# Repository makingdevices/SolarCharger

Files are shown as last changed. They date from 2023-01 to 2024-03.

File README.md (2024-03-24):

<!-- Improved compatibility of back to top link: See: https://github.com/othneildrew/Best-README-Template/pull/73 -->

<!--
*** Thanks for checking out the Best-README-Template. If you have a suggestion
*** that would make this better, please fork the repo and create a pull request
*** or simply open an issue with the tag "enhancement".
*** Don't forget to give the project a star!
*** Thanks again! Now go create something AMAZING! :D
-->

<!-- PROJECT SHIELDS -->
<!--
*** I'm using markdown "reference style" links for readability.
*** Reference links are enclosed in brackets [ ] instead of parentheses ( ).
*** See the bottom of this document for the declaration of the reference variables
*** for contributors-url, forks-url, etc. This is an optional, concise syntax you may use.
*** https://www.markdownguide.org/basic-syntax/#reference-style-links
-->
[][ig-url]
[][sponsor-url]
[][stars-url]
[][issues-url]
[][linkedin-url]

<!-- PROJECT LOGO -->
<br />
<div align="center">
  <a href="https://makingdevices.com/links/">
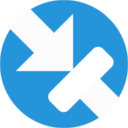
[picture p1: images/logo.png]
    
  </a>

<h3 align="center">Making Devices</h3>

  <p align="center">
    Open Source projects where we struggle with engineering, electronics, coding and who knows what else... The solar charger uses the energy from a solar panel (using MPPT) to charge a Li-Ion rechargeable battery and provide an stable 5V - 0.6A output.
  </p>
</div>

<!-- TABLE OF CONTENTS -->
<details>
  <summary>Table of Contents</summary>
  <ol>
    <li>
      <a href="#about-the-project">About The Project</a>
      <ul>
        <li><a href="#built-with">Built With</a></li>
      </ul>
    </li>
    <li>
      <a href="#Build-one">Build one</a>
      <ul>
      </ul>
    </li>
    <li><a href="#usage">Usage</a></li>
    <li><a href="#roadmap">Roadmap</a></li>
    <li><a href="#license">License</a></li>
    <li><a href="#contact">Contact</a></li>
    <li><a href="#Sponsor">Sponsor</a></li>
  </ol>
</details>

<!-- ABOUT THE PROJECT -->
## About The Project

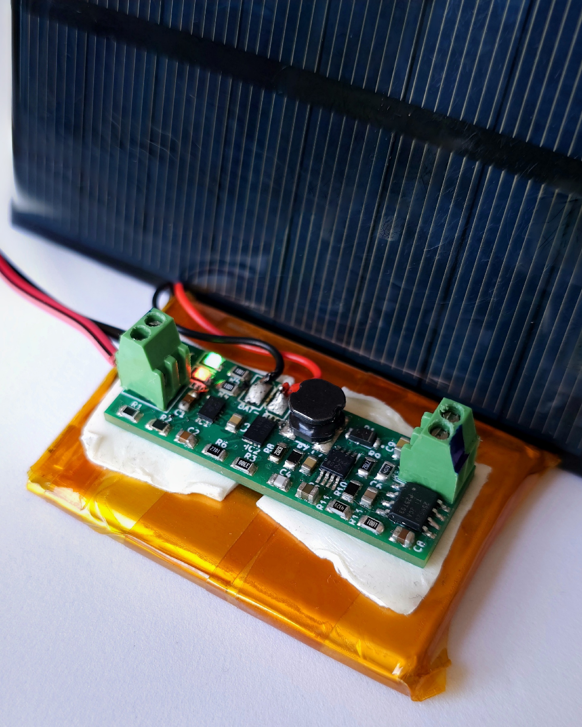
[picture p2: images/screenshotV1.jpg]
Bytes Counter Shot
[](https://github.com/makingdevices/SolarCharger)

The solar charger uses the energy from a solar panel (using MPPT) to charge a Li-Ion rechargeable battery and provide an stable 5V - 0.6A output. The project was created to test a small circuit before using it with other projects. 

<p align="right">(<a href="#readme-top">back to top</a>)</p>

### Built With

[][kicad-url]
[][sponsor-url]

<p align="right">(<a href="#readme-top">back to top</a>)</p>

<!-- GETTING STARTED -->

## Build one
Documentation is updated.

1. Get the gerber files for the latest version: [V1.0](https://github.com/makingdevices/SolarCharger/blob/main/Gerber/SolarCharger_v1.zip) 
2. Send them to a PCB manufacturer ([Our Sponsor is PCBWAY][sponsor-url])
3. You should solder all the components in the board. ([The schematic is available here v1.0][schematic-url])

<p align="right">(<a href="#readme-top">back to top</a>)</p>

<!-- USAGE EXAMPLES -->
## Usage

As soon as you connect a battery, the output voltage will be activated. 

Protections:

- Solar Panel
  - Input voltage from 3V to 20V. It has over-voltage protection (OVP).
  - NTC Sensor: The charging process is compatible with the JEITA temperature standard for Li-Ion batteries, limiting the charge of the battery depending of the temperature of it.
  - Protection for short-circuit in the battery.

- Battery
  - Overcharge Detection Voltage at 4.2V (25mV accuracy)
  - Overcharge Hysteresis Voltage Range. (Release at 4.1V)
  - Overdischarge Detection Voltage at 2.5V.
  - Overdischarge Hysteresis Voltage Range. (Release at 3.0V)
  - Discharge overcurrent detection voltage. 
  - Short current detection voltage.    
  Note: You may want to select a different AP9214 configuration depending of your battery type. We have tested the AP9214L-AE-HSB.

- Output
  - Voltage fixed at 5V +-1.5%
  - Undervoltage protection. 
  - Overvoltage protection at 5.7V
  - Overcurrent and shortcircuit protection (+1A). It will recuperate when the shortcircuit is released. 

<p align="right">(<a href="#readme-top">back to top</a>)</p>

<!-- ROADMAP -->
## Roadmap

- [x] Assembly New Board
- [x] Test with electronic Load.
- [x] Validate ratings

See the [open issues](https://github.com/makingdevices/SolarCharger/issues) for a full list of proposed features (and known issues).

State: Project <b>FINISHED</b> - 12/09/2023

Priority: <b>High</b>

<p align="right">(<a href="#readme-top">back to top</a>)</p>

<!-- LICENSE -->
## License

Distributed under three licenses:
- [Hardware](/License/HW_cern_ohl_s_v2.pdf)
- [Software](/License/SW_GPLv3.0.txt)
- [Documentation](/License/Documentation_CC-BY-SA-4.0.txt)

[GPL v3 License][license-url] 
<p align="right">(<a href="#readme-top">back to top</a>)</p>

<!-- CONTACT -->
## Contact

Making Devices - [@MakingDevices](https://www.instagram.com/makingdevices/)

Project Link: [https://github.com/makingdevices/SolarCharger](https://github.com/makingdevices/SolarCharger/)

Other Links: [LinkTree](https://makingdevices.com/links/)

<p align="right">(<a href="#readme-top">back to top</a>)</p>

<!-- Sponsor -->
## Sponsor

[PCBWAY](https://www.pcbway.com/?from=makingdevices) is the most professional PCB manufacturer for prototyping and low-volume production to work with in the world. With more than a decade in the field, They are committed to meeting the needs of their customers from different industries in terms of quality, delivery, cost-effectiveness and any other demanding requests. As Sponsor of Making Devices, they will be in charge of all the PCBs for MDV, allowing both of us to grow together in a long term partnership. We hope you take them into account for your both personal and professional prototypes or products.

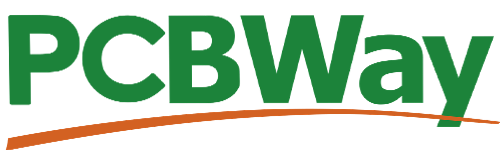
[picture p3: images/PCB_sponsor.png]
Sponsor Shot
[][sponsor-url]

<!-- MARKDOWN LINKS & IMAGES -->
<!-- https://www.markdownguide.org/basic-syntax/#reference-style-links -->
[contributors-shield]: https://img.shields.io/github/contributors/makingdevices/SolarCharger.svg?style=for-the-badge
[contributors-url]: https://github.com/makingdevices/SolarCharger/graphs/contributors
[forks-shield]: https://img.shields.io/github/forks/makingdevices/SolarCharger.svg?style=for-the-badge
[forks-url]: https://github.com/makingdevices/SolarCharger/network/members
[stars-shield]: https://img.shields.io/github/stars/makingdevices/SolarCharger.svg?style=for-the-badge
[stars-url]: https://github.com/makingdevices/SolarCharger/stargazers
[issues-shield]: https://img.shields.io/github/issues/makingdevices/SolarCharger.svg?style=for-the-badge
[issues-url]: https://github.com/makingdevices/SolarCharger/issues
[license-shield]: /images/license.png
[license-url]: https://github.com/makingdevices/SolarCharger/tree/main/License
[linkedin-shield]: https://img.shields.io/badge/-LinkedIn-black.svg?style=for-the-badge&logo=linkedin&colorB=555
[linkedin-url]: https://www.linkedin.com/company/making-devices/
[sponsor-shield]: https://img.shields.io/badge/SPONSOR-PCBWAY-black.svg?style=for-the-badge&colorB=1200
[sponsor-url]: https://www.pcbway.com/?from=makingdevices
[sponsor-screenshot]: /images/PCB_sponsor.png
[product-screenshot]: images/screenshotV1.jpg
[PIC]: https://img.shields.io/badge/PIC18LF45K50-000000?style=for-the-badge
[PIC-url]: http://ww1.microchip.com/downloads/en/devicedoc/40001350f.pdf
[kicad-shield]: https://img.shields.io/badge/kicad-0b03fc?style=for-the-badge&logo=kicad&logoColor=white
[kicad-url]: https://www.kicad.org/
[YT-screenshot]: images/YT_assembly.PNG
[sponsor-icon]:  https://img.shields.io/badge/-PCBWAY-black.svg?style=for-the-badge&colorB=1200
[ig-shield]: https://img.shields.io/badge/instagram-a83297?style=for-the-badge&logo=instagram&logoColor=white
[ig-url]: https://www.instagram.com/makingdevices/
[MPLAB-C]: https://img.shields.io/badge/MPLAB%20C18-DD0031?style=for-the-badge&logo=C&logoColor=white
[MPLAB-C-url]: https://www.microchip.com/en-us/development-tool/SW006011
[Svelte.dev]: https://img.shields.io/badge/Svelte-4A4A55?style=for-the-badge&logo=svelte&logoColor=FF3E00
[Svelte-url]: https://svelte.dev/
[Laravel.com]: https://img.shields.io/badge/Laravel-FF2D20?style=for-the-badge&logo=laravel&logoColor=white
[Laravel-url]: https://laravel.com
[Bootstrap.com]: https://img.shields.io/badge/Bootstrap-563D7C?style=for-the-badge&logo=bootstrap&logoColor=white
[Bootstrap-url]: https://getbootstrap.com
[JQuery.com]: https://img.shields.io/badge/jQuery-0769AD?style=for-the-badge&logo=jquery&logoColor=white
[JQuery-url]: https://jquery.com 
[schematic-url]: /Output_PDF/schematic_V1.pdf

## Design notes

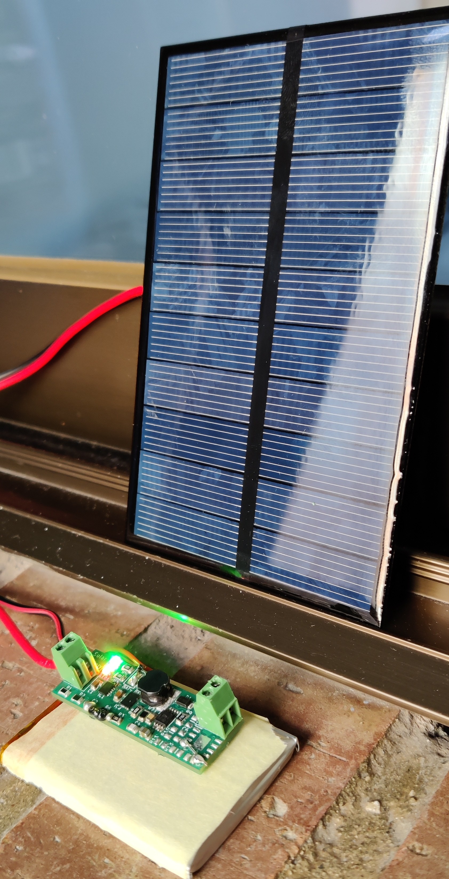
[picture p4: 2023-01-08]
images/screenshot.jpg

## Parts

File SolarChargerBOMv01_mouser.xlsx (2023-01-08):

Part | Info | Qty. | Unit Price | Ext. Price | Mouser Ref | Link
BQ24210DQCR | Charging IC | 1 | $2.4900 | $2.4900 | 595-BQ24210DQCR
NTC 10K 5% | NTC | 1 | $1.1500 | $1.1500 | 279-NTC0805J10K
Resistor 780 |  | 1 | $0.2980 | $0.2980 | 667-ERA-6AEB8060V
Resistor 21.5k |  | 1 | $0.1580 | $0.1580 | 71-CRCW0805-21.5K-E3
resistor 1k |  | 2 | $0.0880 | $0.1760 | 603-RC0805FR-071KL
Capacitor 1uF |  | 2 | $0.1930 | $0.3860 | 581-0805YG105Z
TPS61085 | Step-up 2A | 1 | $2.0700 | $2.0700 | 595-TPS61085TDGKR
FSV360FP | Schottky diode | 1 | $0.4460 | $0.4460 | 512-FSV360FP
47uH Inductor | Coil | 1 | $0.5160 | $0.5160 | 652-SRN6045-4R7Y
Resistor 330 |  | 1 | $0.2280 | $0.2280 | 652-CMP0805AFX-3300L
Resistor 2.7k |  | 1 | $0.1310 | $0.1310 | 71-CRCW0805-2.7K
Resistor 44.2k |  | 1 | $0.1580 | $0.1580 | 71-CRCW0805-44.2K-E3
Resistor 27k |  | 1 | $0.1050 | $0.1050 | 603-RT0805FRE1327KL
Resistor 82k |  | 1 | $0.0880 | $0.0880 | 603-RC0805FR-0782KL
Capacitor 22uF | 6.3VDC | 1 | $0.2450 | $0.2450 | 963-JMK212BBJ226MG8T
Capacitor 820pF | 50VDC | 1 | $0.3060 | $0.3060 | 581-08055A821K
Capacitor 47uF |  | 1 | $1.0900 | $1.0900 | 581-0805ZD476MAT2A
Capacitor 100nF |  | 1 | $0.1400 | $0.1400 | 581-08055C104K
AP9214L | Battery Prot. IC | 1 | $0.8400 | $0.8400 | 621-AP9214L-AN-HSBR7
TPS259620DDAR | eFuse | 1 | $0.8050 | $0.8050 | 595-TPS259620DDAR
Resistor 450k |  | 1 | $0.1580 | $0.1580 | 71-CRCW0805453KFKEA
Resistor 432k |  | 1 | $0.0880 | $0.0880 | 652-CR0805FX-4323ELF
Capacitor 2.2nF |  | 1 | $0.2360 | $0.2360 | 80-C0805C222K2GECTU
Capacitor 100uF |  | 1 | $0.1140 | $0.0960 | 80-C0805C104K5RACLR
Resistor 400k |  | 1 | $0.0960 | $0.0880 | 667-ERJ-6ENF4023V
Resistor 909 |  | 1 | $0.0880 | $0.0880 | 652-CR0805FX-9090ELF
Connector 2P | Screw terminals | 2 | $1.1200 | $2.2400 | 571-282834-2
 |  |  |  | Total: | $14.8200

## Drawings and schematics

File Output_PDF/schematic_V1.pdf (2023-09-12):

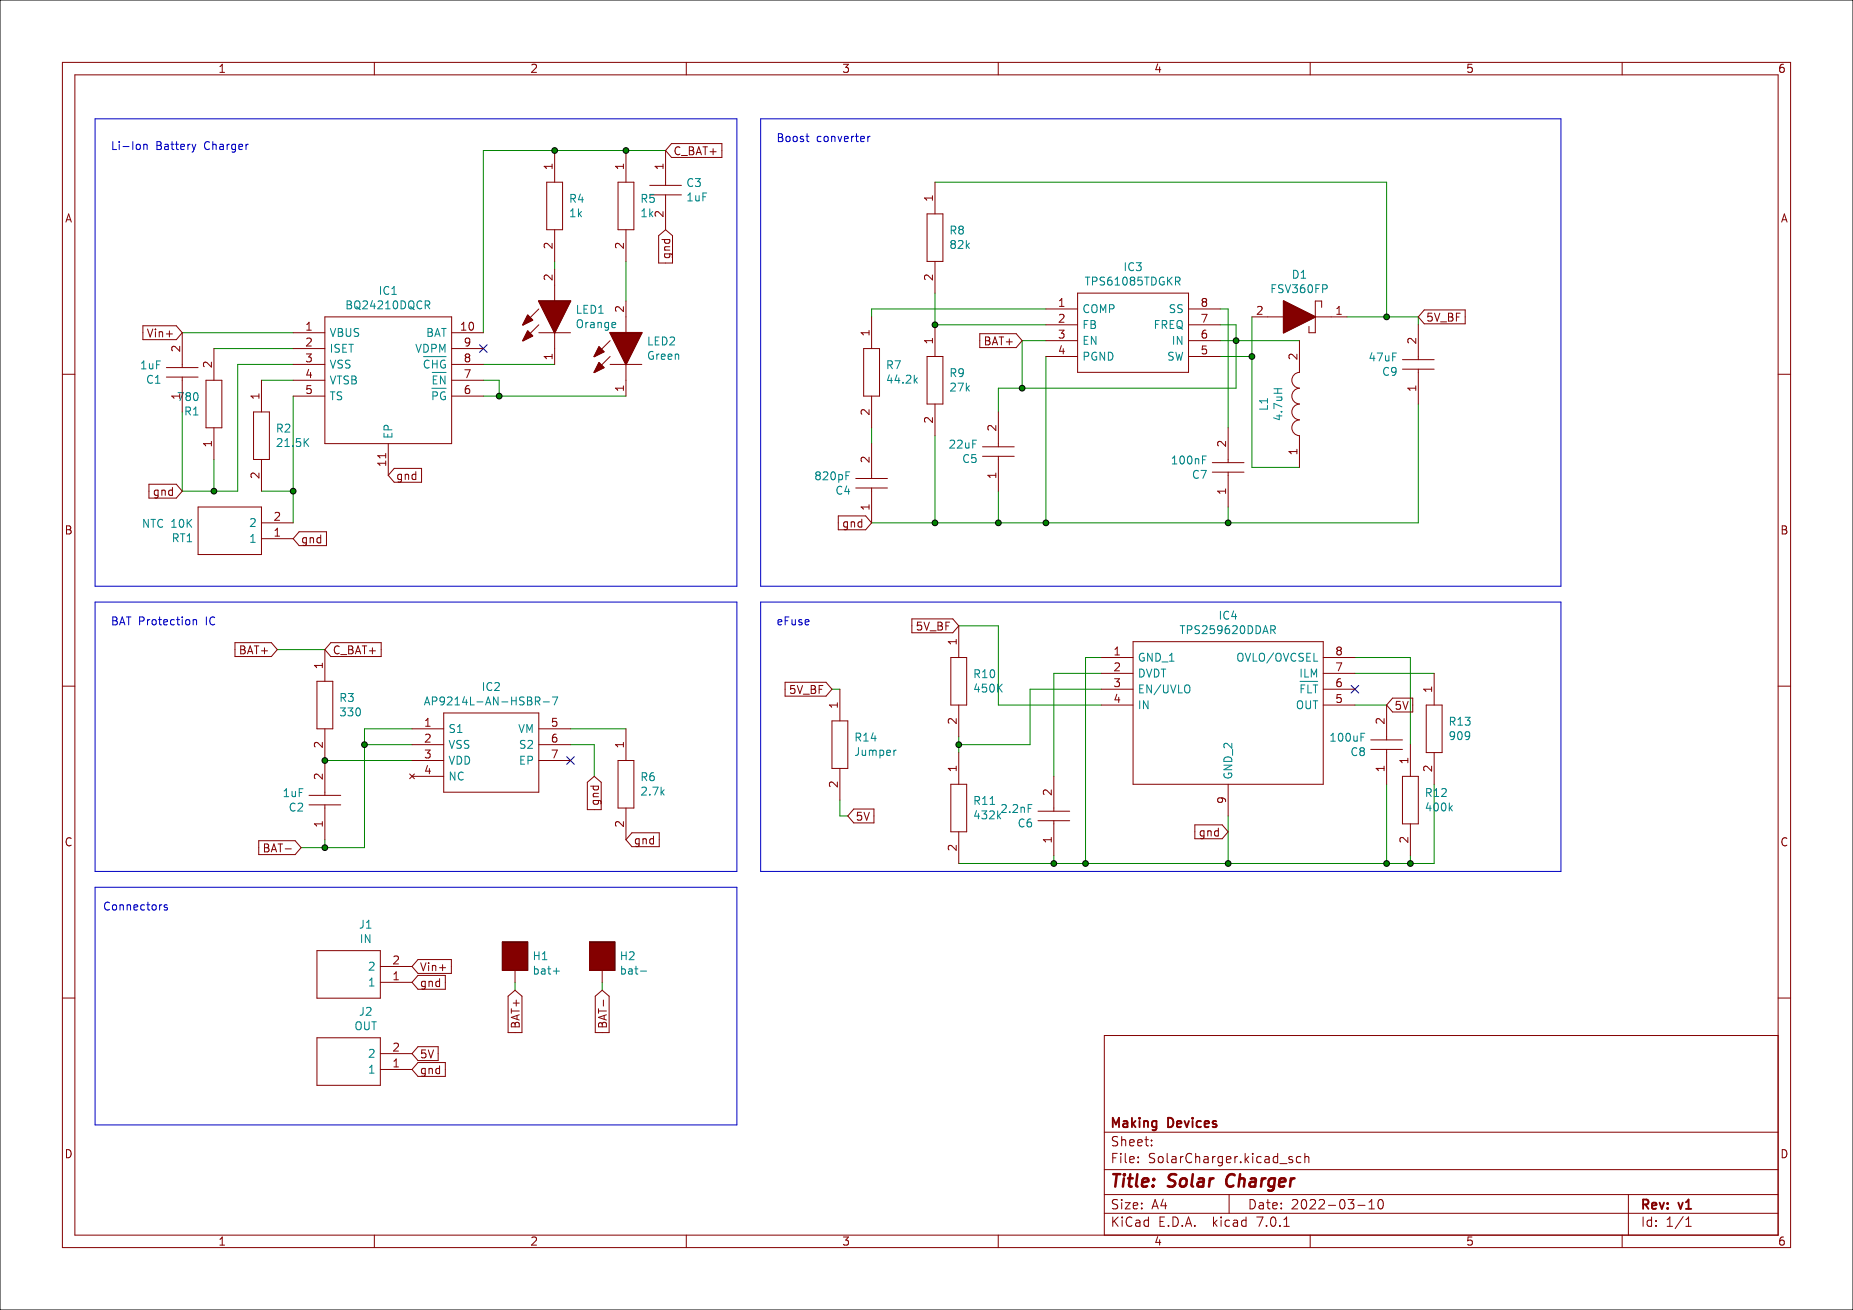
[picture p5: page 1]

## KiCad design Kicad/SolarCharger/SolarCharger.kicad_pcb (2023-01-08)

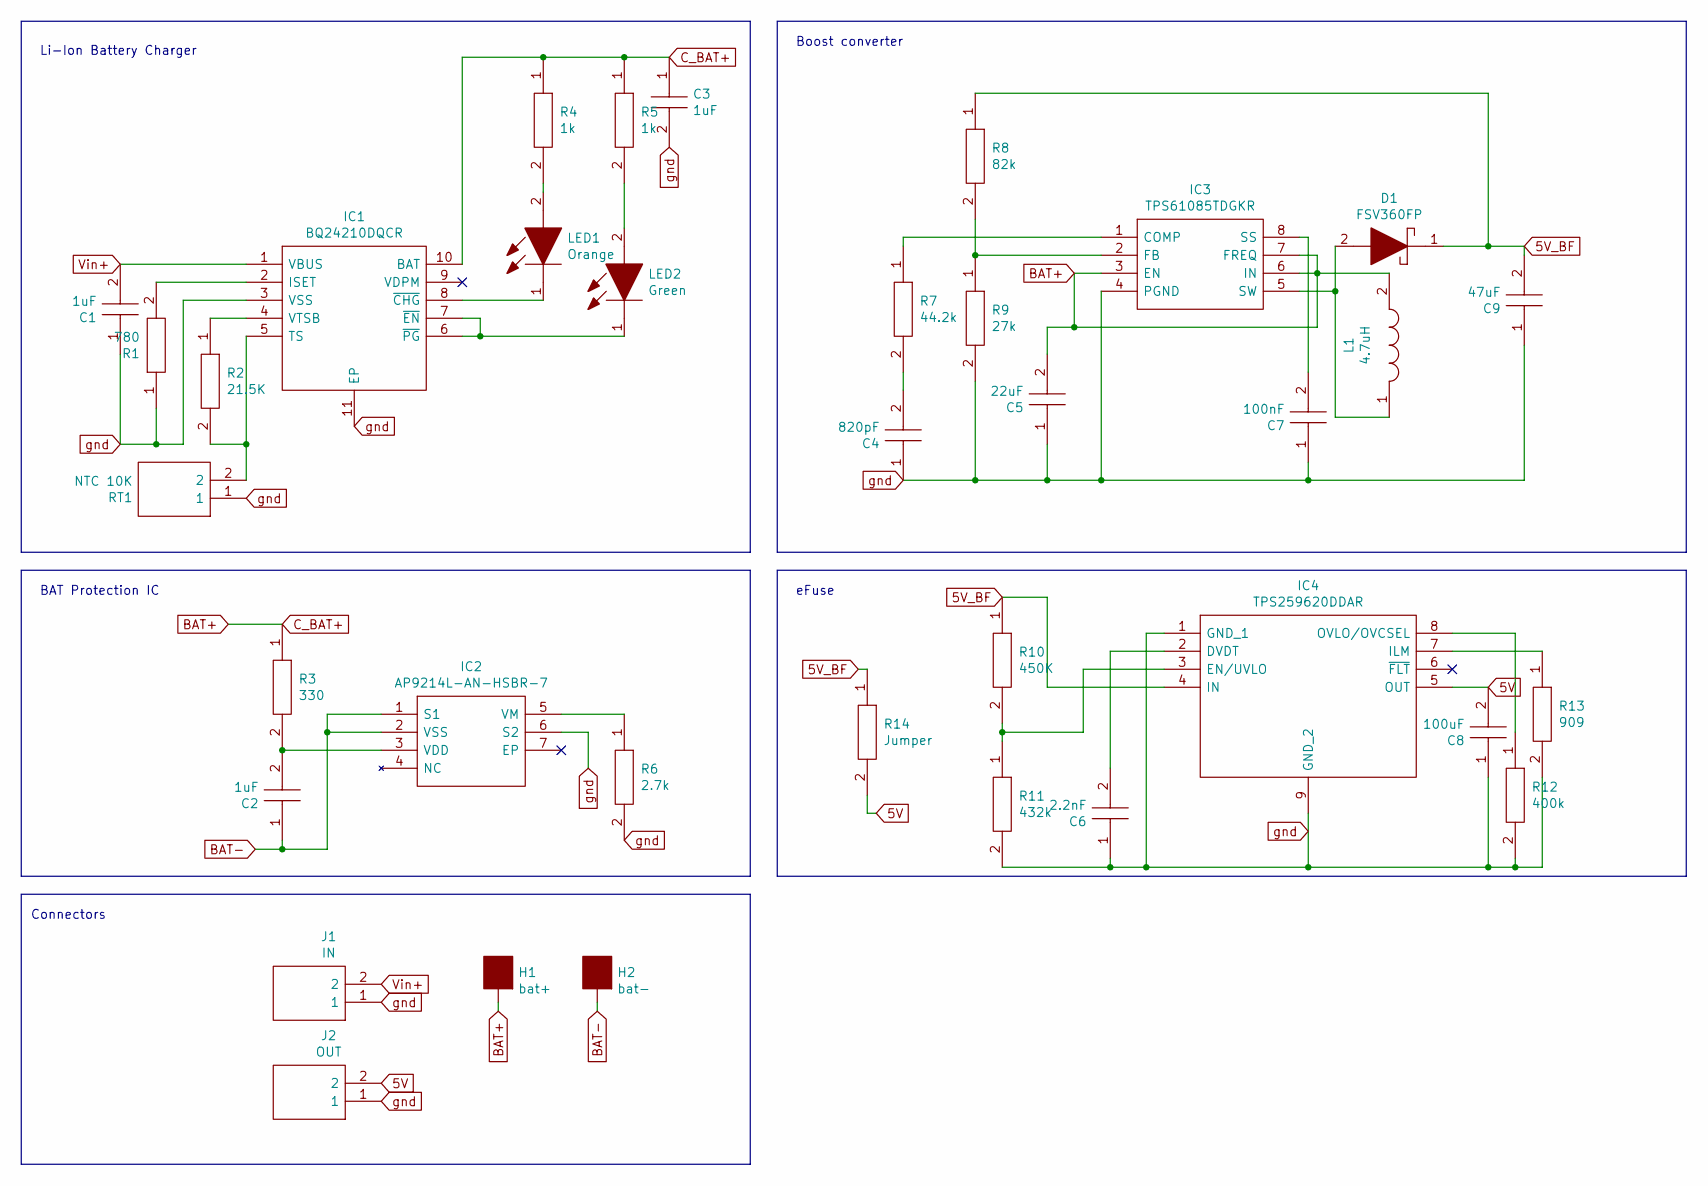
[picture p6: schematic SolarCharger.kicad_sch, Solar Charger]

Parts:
C1, C2, C3: 1uF; CAPC2012X140N; Manufacturer_Part_Number C0805C475M8RACTU
C4: 820pF; CAPC2012X140N; Manufacturer_Part_Number C0805C475M8RACTU
C5: 22uF; CAPC2012X140N; Manufacturer_Part_Number C0805C475M8RACTU
C6: 2.2nF; CAPC2012X140N; Manufacturer_Part_Number C0805C475M8RACTU
C7: 100nF; CAPC2012X140N; Manufacturer_Part_Number C0805C475M8RACTU
C8: 100uF; CAPC2012X140N; Manufacturer_Part_Number C0805C475M8RACTU
C9: 47uF; CAPC2012X140N; Manufacturer_Part_Number C0805C475M8RACTU
D1: FSV360FP; SS12FP; Mouser Part Number 512-FSV360FP
H1: bat+; mountinghole_battery
H2: bat-; mountinghole_battery
IC1: BQ24210DQCR; SON50P200X300X80-11N; Mouser Part Number 595-BQ24210DQCR
IC2: AP9214L-AN-HSBR-7; AP9214LANHSBR7; Mouser Part Number 621-AP9214L-AN-HSBR7
IC3: TPS61085TDGKR; SOP65P490X110-8N; Mouser Part Number 595-TPS61085TDGKR
IC4: TPS259620DDAR; SOIC127P600X170-9N; Mouser Part Number 595-TPS259620DDAR
J1: IN; 282834-2_1; Mouser Part Number 571-282834-2
J2: OUT; 282834-2_1; Mouser Part Number 571-282834-2
L1: 4.7uH; SRN6045_1; Mouser Part Number 652-SRN6045-4R7Y
LED1: Orange; LEDC2012X90N; Manufacturer_Part_Number SML-H12V8TT86
LED2: Green; LEDC2012X90N; Manufacturer_Part_Number SML-H12V8TT86
R1: 780; RESC2012X75N; Manufacturer_Part_Number ERJP6WF1303V
R2: 21.5K; RESC2012X75N; Manufacturer_Part_Number ERJP6WF1303V
R3: 330; RESC2012X75N; Manufacturer_Part_Number ERJP6WF1303V
R4, R5: 1k; RESC2012X75N; Manufacturer_Part_Number ERJP6WF1303V
R6: 2.7k; RESC2012X75N; Manufacturer_Part_Number ERJP6WF1303V
R7: 44.2k; RESC2012X75N; Manufacturer_Part_Number ERJP6WF1303V
R8: 82k; RESC2012X75N; Manufacturer_Part_Number ERJP6WF1303V
R9: 27k; RESC2012X75N; Manufacturer_Part_Number ERJP6WF1303V
R10: 450K; RESC2012X75N; Manufacturer_Part_Number ERJP6WF1303V
R11: 432k; RESC2012X75N; Manufacturer_Part_Number ERJP6WF1303V
R12: 400k; RESC2012X75N; Manufacturer_Part_Number ERJP6WF1303V
R13: 909; RESC2012X75N; Manufacturer_Part_Number ERJP6WF1303V
R14: Jumper; RESC2012X75N; Manufacturer_Part_Number ERJP6WF1303V
RT1: NTC 10K; THRMC2012X95N; Mouser Part Number 594-NTCS0805E3103GMT

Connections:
5V: C8.2, IC4.5 (OUT), J2.2, R14.2
5V_BF: C9.2, D1.1, IC4.4 (IN), R8.1, R10.1, R14.1
BAT+: C3.1, C5.2, H1.1, IC1.10 (BAT), IC3.3 (EN), IC3.6 (IN), IC3.7 (FREQ), L1.2, R3.1, R4.1, R5.1
BAT-: C2.1, H2.1, IC2.1 (S1), IC2.2 (VSS)
unnamed: C2.2, IC2.3 (VDD), R3.2
unnamed: C4.2, R7.2
unnamed: C6.2, IC4.2 (DVDT)
unnamed: C7.2, IC3.8 (SS)
unnamed: D1.2, IC3.5 (SW), L1.1
unnamed: IC1.2 (ISET), R1.2
unnamed: IC1.4 (VTSB), R2.1
unnamed: IC1.5 (TS), R2.2, RT1.2
unnamed: IC1.6 (~PG), IC1.7 (~EN), LED2.1
unnamed: IC1.8 (~CHG), LED1.1
unnamed: IC2.5 (VM), R6.1
unnamed: IC3.1 (COMP), R7.1
unnamed: IC3.2 (FB), R8.2, R9.1
unnamed: IC4.3 (EN/UVLO), R10.2, R11.1
unnamed: IC4.7 (ILM), R13.1
unnamed: IC4.8 (OVLO/OVCSEL), R12.1
unnamed: LED1.2, R4.2
unnamed: LED2.2, R5.2
Vin+: C1.2, IC1.1 (VBUS), J1.2
gnd: C1.1, C3.2, C4.1, C5.1, C6.1, C7.1, C8.1, C9.1, IC1.3 (VSS), IC1.11 (EP), IC2.6 (S2), IC3.4 (PGND), IC4.1 (GND_1), IC4.9 (GND_2), J1.1, J2.1, R1.1, R6.2, R9.2, R11.2, R12.2, R13.2, RT1.1

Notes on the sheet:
BAT Protection IC
Connectors
eFuse
Li-Ion Battery Charger
Boost converter

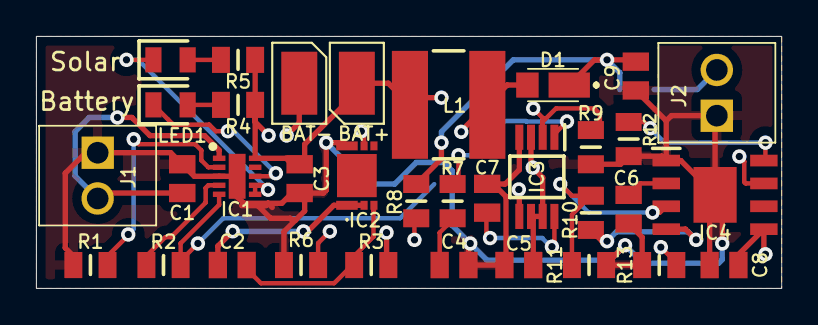
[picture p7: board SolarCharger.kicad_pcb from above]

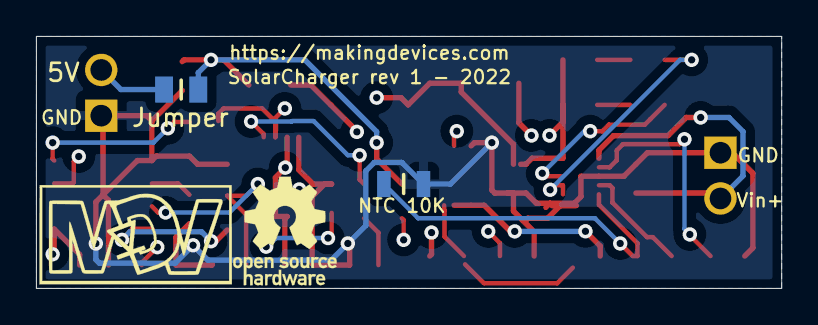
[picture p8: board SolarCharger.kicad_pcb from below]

Board: 4 copper layers, 41.4 x 14.0 mm, 36 parts (2 on the bottom side), 24 nets.

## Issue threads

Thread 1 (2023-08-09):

[Requisite][V1.0] Output Ratings

makingdevices, 2023-08-09:
- [x] The output voltage should be 5V +-1.5%
- [x] The nominal output current should be 0.6A [Without time limit] // Desirable 0.8 A
- [x] The maximum peak current should be 0.9A. [Seconds...]

Closed 2023-09-12.

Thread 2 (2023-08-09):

[Requisite] [V1.0] Input Ratings

makingdevices, 2023-08-09:
- [x] The charger should have MPPT functiont for Solar Panels.
- [x] Voltage range 3-12V
- [x] Maximum input current of 0.5A

makingdevices, 2023-09-07:
The Input is limited to 0.5A. It has MPPT for solar panels. Need to test the voltage range

makingdevices, 2023-09-12:
Works up to 20V and even higher (Overvoltage Protection), but it wont charge for any voltage superior to 7-8V (Over voltage protection from the battery chip)

Closed 2023-09-12.

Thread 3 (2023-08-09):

[Requisite] [V1.0] Protections

makingdevices, 2023-08-09:
- [x] The board should protect the battery against over-discharge.
- [x] The board should protect the battery against shortcircuit at the output.
- [x] The board should protect the battery against over-current (1A limit)

makingdevices, 2023-09-07:
The output protection works as expected.

Closed 2023-09-12.
